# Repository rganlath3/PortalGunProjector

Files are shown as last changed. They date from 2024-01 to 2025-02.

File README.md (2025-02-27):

# Portal Gun Embedded Projector



[]()

A Portal Gun prop featuring an embedded HDMI projector that displays authentic Portal visuals and sounds. This project combines 3D printing, electronics, and software to create a realistic prop that doubles as a portable projector. The portal gun is from popular Valve videogame, Portal / Portal 2.

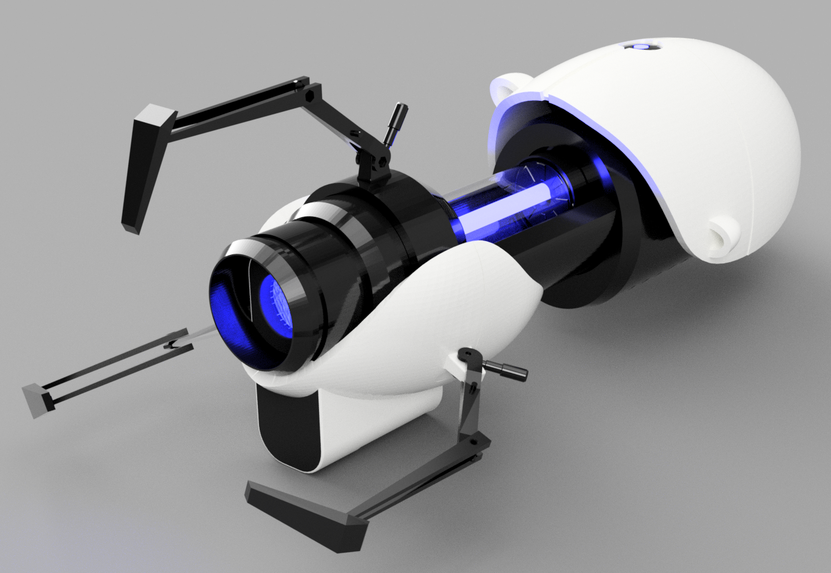
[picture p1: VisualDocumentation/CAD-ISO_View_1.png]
Portal Gun Iso View


<!-- TABLE OF CONTENTS -->
## Table of Contents

<details>
<summary>Table of Contents</summary>

1. [About The Project](#about-the-project)
    - [Design Tools & Requirements](#design-tools--requirements)
        - [Software Requirements](#software-requirements)
        - [Hardware Requirements](#hardware-requirements)
2. [Hardware Development](#hardware-development)
    - [Bill of Materials](#bill-of-materials)
    - [Hardware Used](#hardware-used)
    - [3D Printing the Model](#3d-printing-the-model)
    - [3D Printing Specifications](#3d-printing-specifications)
    - [Model Prep](#model-prep)
    - [Electrical Interconnect Diagram](#electrical-interconnect-diagram)
    - [PCB](#pcb)
    - [Wiring](#wiring)
    - [Power](#power)
3. [Software Development](#software-development)
4. [Getting Started](#getting-started)
    - [Prerequisites](#prerequisites)
    - [Installation](#installation)
    - [Common Issues](#common-issues)
5. [Assets](#assets)
    - [Audio](#audio)
    - [Video](#video)
6. [Roadmap](#roadmap)
7. [Contributing & Donations](#contributing--donations)
8. [License](#license)
9. [Contact](#contact)

</details>

<!-- ABOUT THE PROJECT -->
## About The Project
The idea was to take 3D printing a Portal Gun Prop to the next level of realism. My brother inspired me to create a Prop Portal Gun with an full HDMI Projector inside of the prop. When activated, it displays authentic Portal visuals, produces game-accurate sound effects through integrated speakers, and displays LED effects. The project combines 3D printing, electronics, and software development to create a prop that's both visually accurate and practically useful as a portable projector.

### Design Tools & Requirements

#### Software Requirements
- Python 3.9+ (Programming Language for RPi)
- Raspberry Pi OS Debian v12 (64-bit)
- VS Code (Programming IDE)
- Autodesk Fusion360 (Free CAD Software)
- KiCAD 7 (Open Source PCB Design Software)
- Ultimaker Cura (Free 3D Slicing Software)

#### Hardware Requirements
- Raspberry Pi 4 (8GB RAM recommended)
- 32GB+ SD Card
- 12V Power Supply or 4S Lipo Battery Pack

<p align="right">(<a href="#readme-top">back to top</a>)</p>

## Hardware Development

### Bill of Materials
Coming Soon

### Hardware Used
* Raspberry Pi 4 (SBC)
* Custom RPi HAT PCB (Power and GPIO Distribtuion to Screw Terminals) (See PCB Designs)
* Various Capacitors, Resistors, SMD LEDs, JST Connectors, Wire Crimps, etc.
* Various stranded wire lengths and colors: 16AWG, 22AWG.
* 1x DROK 9V-24V to 5V Step Down Buck Converter, 30W (Powers Pi from Battery Input)
* 1x Songhe 10-32V to 21V Step Up Boost Converter, 150W (Powers Projector from Battery Input)
* 1x 16mm Momentary Metal LED Push Button (Orange)
* 1x 16mm Momentary Metal LED Push Button (Blue)
* 2x 2.1mm DC Barrel Jacks Pair (Power Input)
* 2x SPST 20A Heavy Duty Toggle Switch (Projector Power and Pi Power)
* 1x SPST 5A Mini Toggle Switch (LED Power)
* 1x Individually Addressable 5V NeoPixel
* 1x 1ft. RGB COB Individually Addressable 5V LED Strip 
* Portal Gun 3D Design: (found on thingiverse [here](https://www.thingiverse.com/thing:3579224)) 
* My modifications to the Portal Gun 3D Design.
* 3D Printer: Creality CR-10SProV2

### 3D Printing the Model
I used this portal gun design as a basis for my version. This creator put a lot of work into his design so please give him the attention he deserves: [EVARATE Portal Gun](https://www.thingiverse.com/thing:3579224)

### 3D Printing Specifications

#### Print Settings
- Layer Height: 0.2mm
- Infill: 15% for most parts but 100% for finger parts
- Temperature: 210°C (PLA+)
- Build Plate: 60°C
- Support: Required for overhangs
- Material: eSUN PLA+ or equivalent

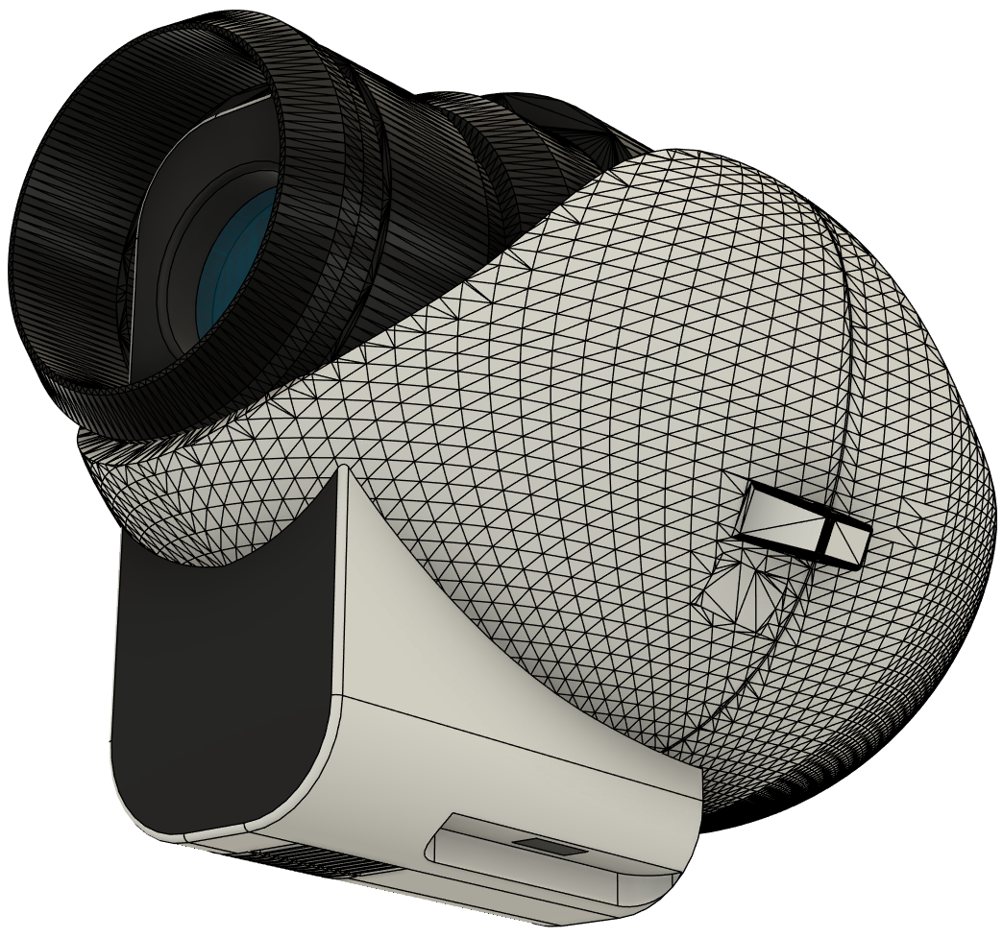
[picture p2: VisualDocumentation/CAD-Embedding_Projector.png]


Besides modifying parts to fit the projector, I also designed an electronics sled to fit the handle base. This is what the DC-DC converters and Raspberry Pi mount to.

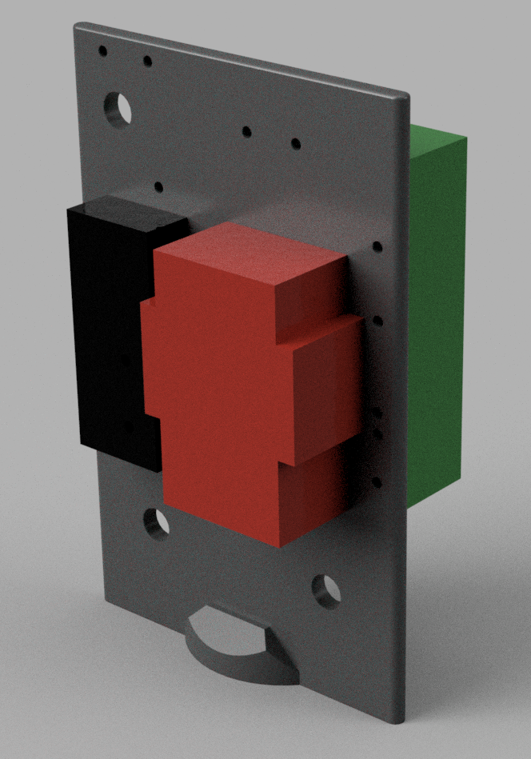
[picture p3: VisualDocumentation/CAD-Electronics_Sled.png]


### Model Prep
Sanding, filler, painting, etc.

* 3M Acryl Putty, 05096 Green or 05098 Red
* Various Sandpaper and Sanding Sponges
* Dremel
* P95 or Better Respirator (don't cheap out on this)
* Filler & Sandable Primer (I use cheap Rust-Oleum)
* Montana Gold Shock White Pure Spray Paint
* Montana Gold Shock Black Spray Paint
* Spray Max USC 2K High Gloss Clearcoat (Automotive Clearcoat, expensive but worth it!)

Once all the parts have been printed, we need to do some post processing to get the prints as smooth as possible. For my first iteration, I used a dremel to manually cut holes in some parts instead of just CADing them out. (I wasn't sure how things would exactly fit.)

*Note: Anytime we are sanding or spray painting, you MUST be wearing that respirator! 
Also try to handle all the parts with rubber gloves so your fingerprints don't mess up the paint coats.*

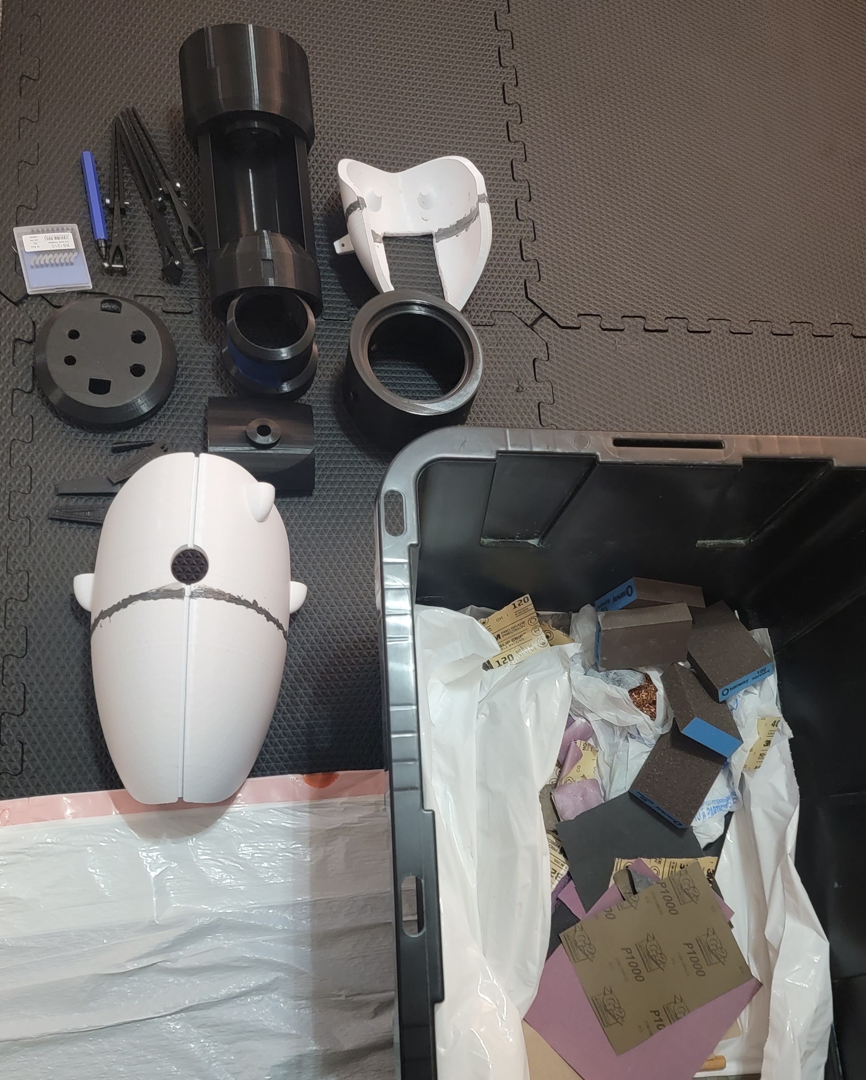
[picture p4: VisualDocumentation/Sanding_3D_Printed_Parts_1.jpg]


Using sanding paper and sponges I used the following grits:
120->220->320->400 using spot putty where needed. Anything above 320 grit should be wet sanded. Then 2x coats of fillable primer spray paint. Then 400 grit. Then 1x coat of fillable primer. Then one more 400 grit. Then 600 grit. Then apply desired paint color (black and white) base coat in many light coats. (3-5 coats) I'd like to try to find an alternate to Montana Gold.

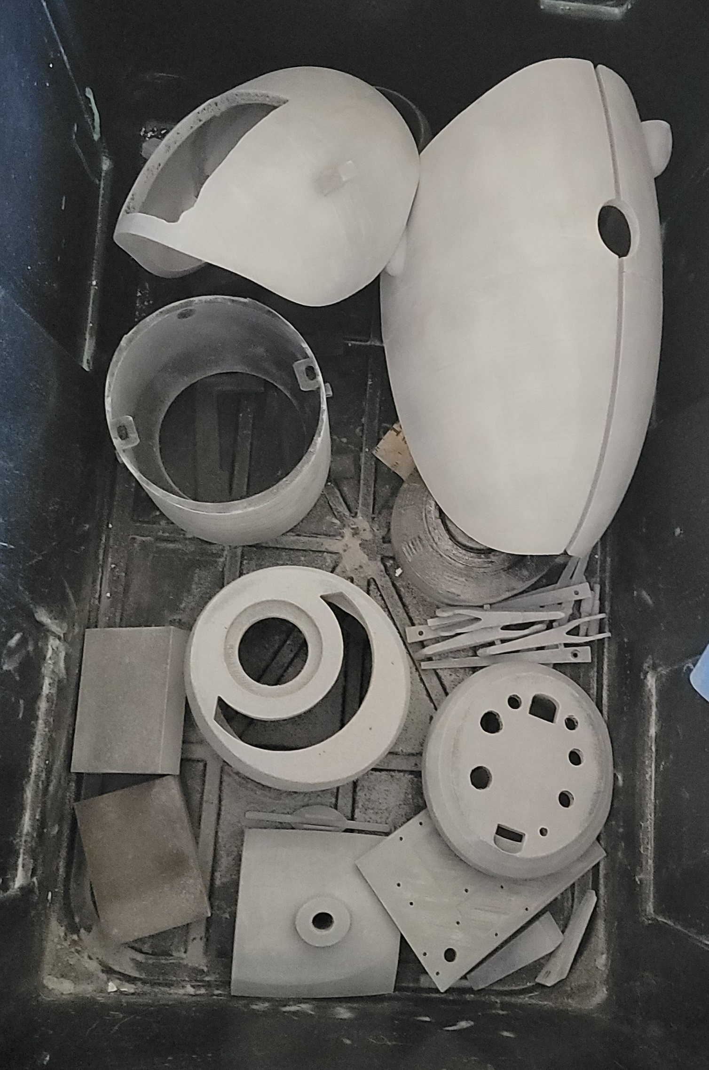
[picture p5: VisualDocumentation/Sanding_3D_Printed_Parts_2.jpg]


Once fully dried, use a damp sponge and wipe the parts. Use 1000 grit to sand down the base coat. 

Optional: Using citadel paints or any acrylic paints, add weathering, scuff marks, or damage. I ended up using a metal file and creating scratches. I finely dry brushed silver paint onto the black parts to create a metallic highlight effect. I also added a white line on the top white part.

Once finished painting, we can now apply layers of clearcoat in a very well ventilated area. This 2K stuff is really toxic so be careful. I ended up using rust-oleum 2x ultracover clear instead which gave a good result but not as nice as 2k would have been. I used gloss clear coat on the white parts and black arms. I used matte clear coat on the black parts. Once fully cured, assembly can begin.

### Electrical Interconnect Diagram
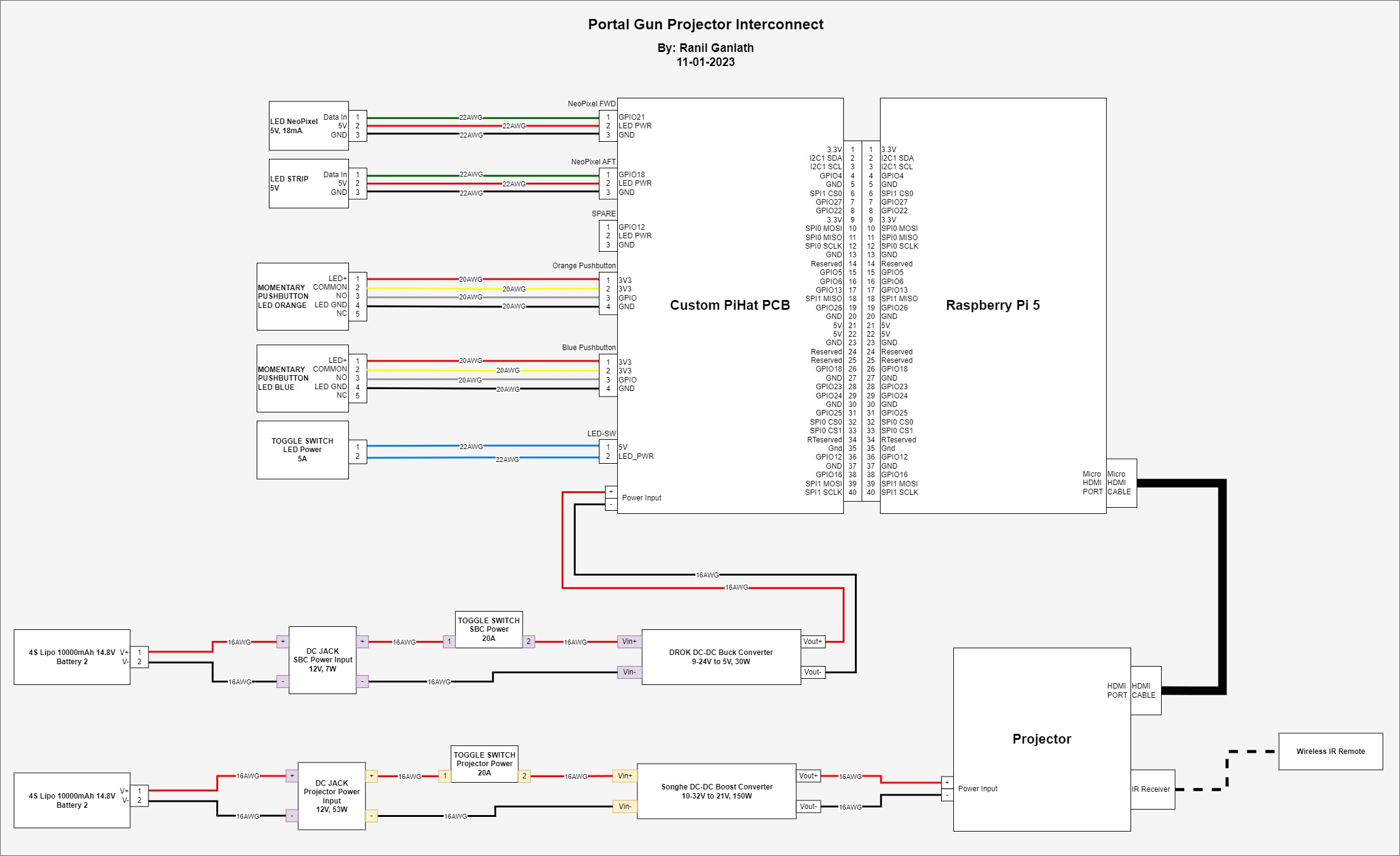
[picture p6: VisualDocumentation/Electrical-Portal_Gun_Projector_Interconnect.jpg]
Electrical Interconnect Diagram


### PCB
I designed a Raspberry Pi Hat PCB that handles powering the board (via 5V pins), powering LEDs, and acting as GPIO inputs/outputs for button inputs and driving neopixels. See Mk2 design for the latest. If I had a chance for another iteration, I would add slotted holes in the center section for the placement of a low profile fan for cooling the raspberry pi.

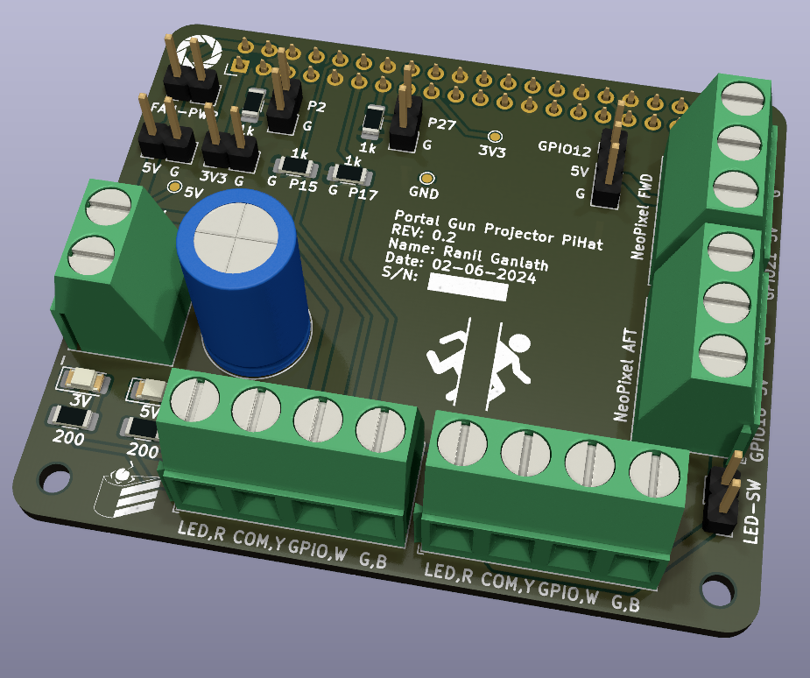
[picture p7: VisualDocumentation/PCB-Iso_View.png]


### Wiring
I used 22AWG and 16AWG for all wiring in the system. 22AWG was used for neopixels and GPIO pins while 16AWG was used for all power lines. 
* Red - Power
* Black - GND
* Green - Data / GPIO

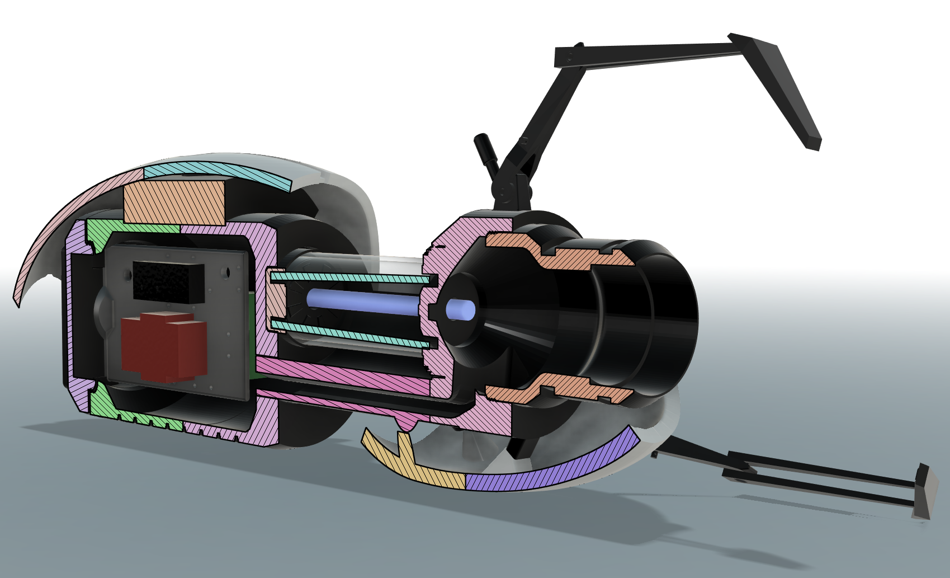
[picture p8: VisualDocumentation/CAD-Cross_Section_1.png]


### Power
I have two separate power circuits: Pi and Projector.

The Pi Circuit runs on 5V. It powers the neopixels, raspberry pi, and push button LEDs.
* Input Voltage: 12V
* Converted Voltage: 5V
* Average Wattage (Script Running): 4.1W
* Theorhetical Max Load: 
* Safety Factor (Max Power * 1.25W): 7W
* Battery Required for 2 hour battery life:

The Projector Circuit runs on 21V. It powers the projector and it's internal speakers.
* Input Voltage: 12V
* Converted Voltage: 21V
* Average Watage (Lamp On): 41.46W
* Theorhetical Max Load:
* Safety Factor (Max Power * 1.25W): 53W
* Battery Required for 2 hour battery life:

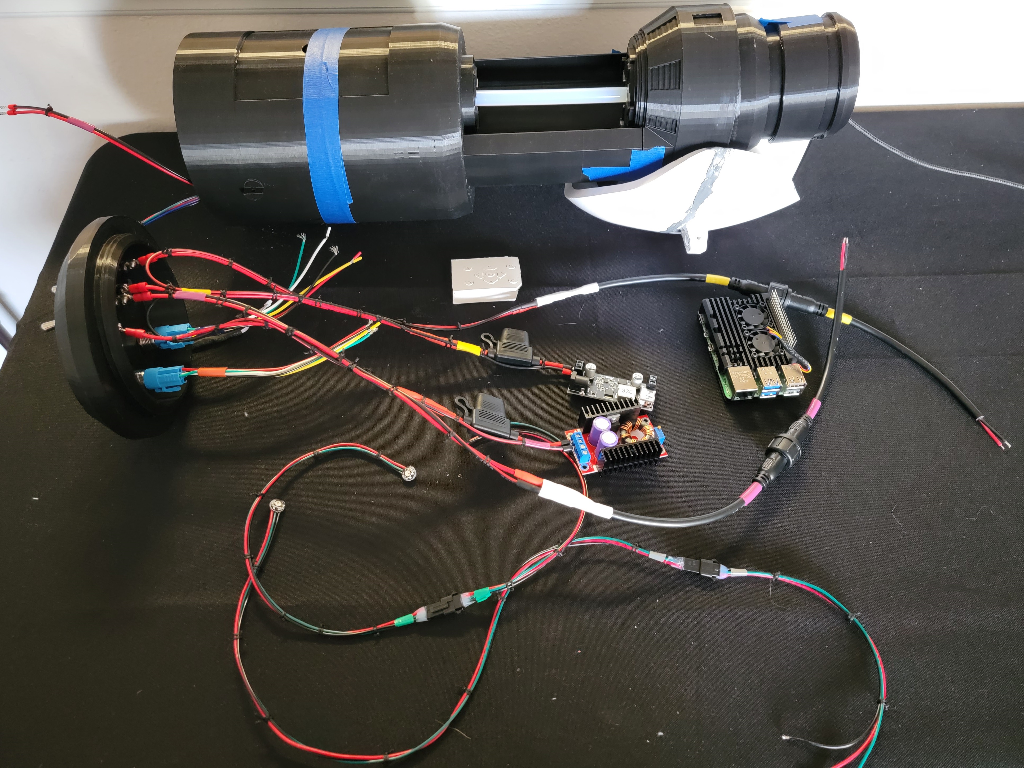
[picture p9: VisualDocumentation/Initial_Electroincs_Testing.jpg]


## Software Development
I am familiar using an Arduino or other MCU to solve all my hardware integration problems. In the past I've used Arduinos + Raspberry Pis when needed (such as for ROS projects). For this project, I wanted to challenge myself to not use any MCUs and to only use the raspberry pi GPIO pins to interact with switches and LED control. It brought up some fun compatibility issues that prevented me from using a Raspberry Pi 5 until libraries were updated. 

***Disclaimer: I am an electrical engineer, so apologies for the chaos that is my programming.***

<!-- GETTING STARTED -->
## Getting Started

* Install Raspberry Pi OS with Desktop (Debian v12) (64-bit)
  * we will use the desktop version for initial setup then switch to the CLI for actual operation. This saves time when troubleshooting things like VLC issues.
* Copy this repo to any desired folder. 
  * For reference, my filepath was: */home/aperture/Documents/PortalGunProjector*

### Prerequisites
*Note: Since Neopixel Usage requires root priviledges, make sure your environment path is configured accordingly. I recommend installing all these python libraries as root (sudo command). It is possible to run sudoless but it requires using only GPIO10 for LEDs*

```bash
# Update System
sudo apt update && sudo apt upgrade -y

# Install Required Packages
sudo apt install git python3-pip vlc -y

# Install Python Dependencies

# Raspberry PI GPIO Control
sudo pip3 install gpiozero

# NeoPixel Drivers
sudo pip3 install adafruit-circuitpython-neopixel

# Pygame
sudo pip3 install pygame

# VLC
sudo apt install vlc

# VLC Python Bindings
sudo pip3 install python-vlc
```

### Installation

1. If you haven't already, clone the repo, to a directory such as: */home/username/Documents/PortalGunProjector*

   ```sh
   git clone https://github.com/rganlath3/PortalGunProjector.git
   ```
2. Install prequisites listed above.

3. Run each test script to test functionality as you build, then run launch.py

<p align="right">(<a href="#readme-top">back to top</a>)</p>

### Common Issues

1. LED Control Fails
```bash
# Check permissions
sudo usermod -a -G gpio $USER
# Reboot required after permission change
```

2. Video Playback Issues
- Ensure micro HDMI port used is closest to USB-C power connector.
- Check video codec compatibility
- Verify file permissions

## Assets

### Audio
The portal gun plays audio out of the hdmi audio output via the projector speakers. Everytime a button is pressed, a random soundclip from a list will play to add some variety to mashing buttons. All audio files are in the "Sounds" folder and are extracted from in game. I do not own these files.

### Video
On bootup a random video and audio line will play as an initialization. On button presses, a random sized orange or blue portal video will play on loop. I manually created these videos by screen recording Garry's Mod and careful editing. Bootup videos are sourced from Portal Gameplay and Trailers from Value and are not owned by me. 

<!-- ROADMAP -->
## Roadmap
- [x] CAD Small Projector
- [x] Modify Portal Gun Designs
- [x] Design electrical interconnect
- [x] 3D Print all parts
- [x] Sanding and post processing on parts
- [x] Painting all parts
- [x] Redesign electrical interconnect
- [x] Create Electronics Sled
- [x] Create wiring harness
- [x] Test LED effects
- [x] Integrate pushbuttons into programming
- [x] Create portal and bootup videos
- [x] Configure code to run on startup
- [x] Add Visual Documentation to GitHub
- [x] Assemble Portal Gun
- [x] Final tests with benchtop power supply
- [ ] Add magnets and external cables
- [ ] Create Battery Harness

<p align="right">(<a href="#readme-top">back to top</a>)</p>

<!-- CONTRIBUTING -->
## Contributing & Donations

Any donation helps to support parts for future open source projects!
[Buy Me a Coffee ☕](https://www.buymeacoffee.com/rganlath)

Contributions are what make the open source community such an amazing place to learn, inspire, and create. Any contributions you make are **greatly appreciated**.

If you have a suggestion that would make this better, please fork the repo and create a pull request. You can also simply open an issue with the tag "enhancement".
Don't forget to give the project a star! Thanks again!

<p align="right">(<a href="#readme-top">back to top</a>)</p>

<!-- LICENSE -->
## License
The contents of this project itself is licensed under CERN-OHL-S-2.0 and the underlying source code used for programming the raspberry pi is licensed under GNU GPLv3. Both of these licenses require attribution.

<p align="right">(<a href="#readme-top">back to top</a>)</p>

<!-- CONTACT -->
## Contact

Ranil Ganlath - ranil.ganlath@gmail.com

Project Link: [https://github.com/rganlath3/PortalGunProjector](https://github.com/rganlath3/PortalGunProjector)

<p align="right">(<a href="#readme-top">back to top</a>)</p>

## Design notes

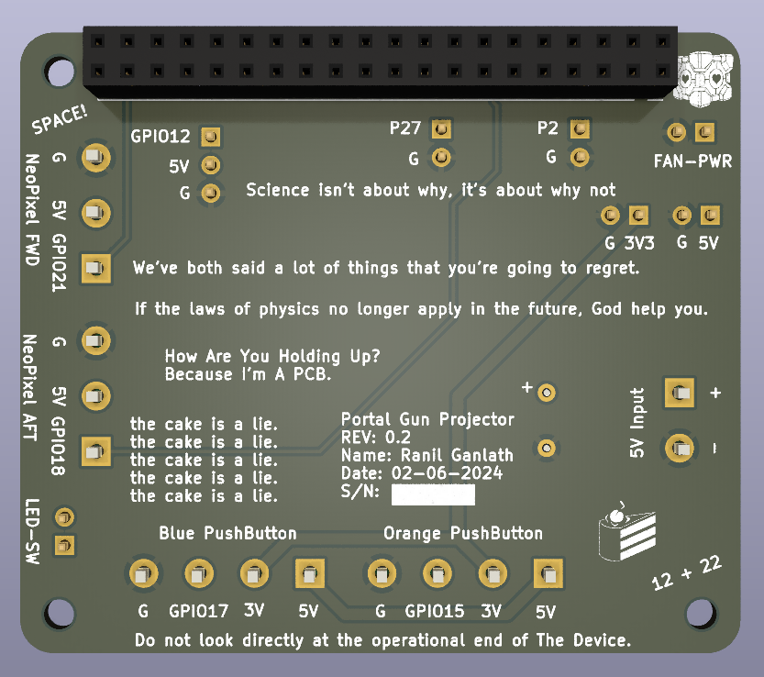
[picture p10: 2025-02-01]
VisualDocumentation/PCB-Bottom_View.png

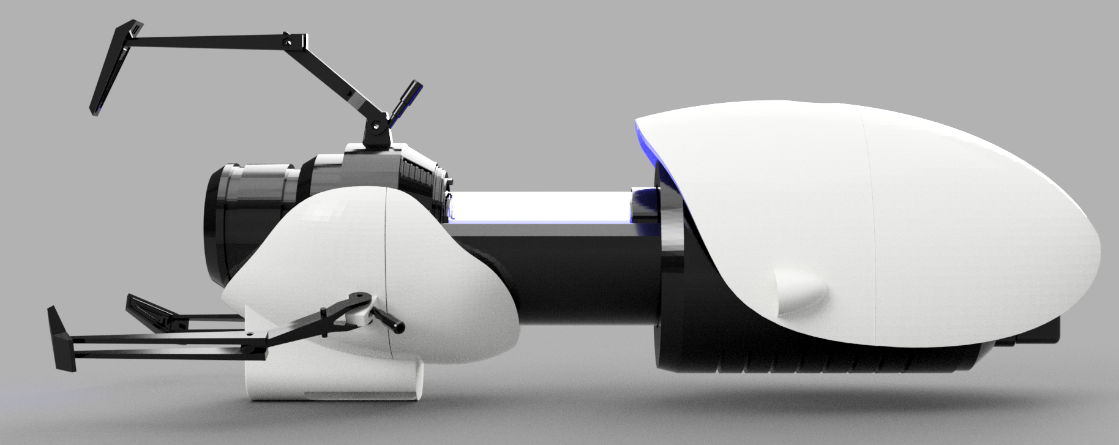
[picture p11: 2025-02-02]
VisualDocumentation/CAD-Side_View.png

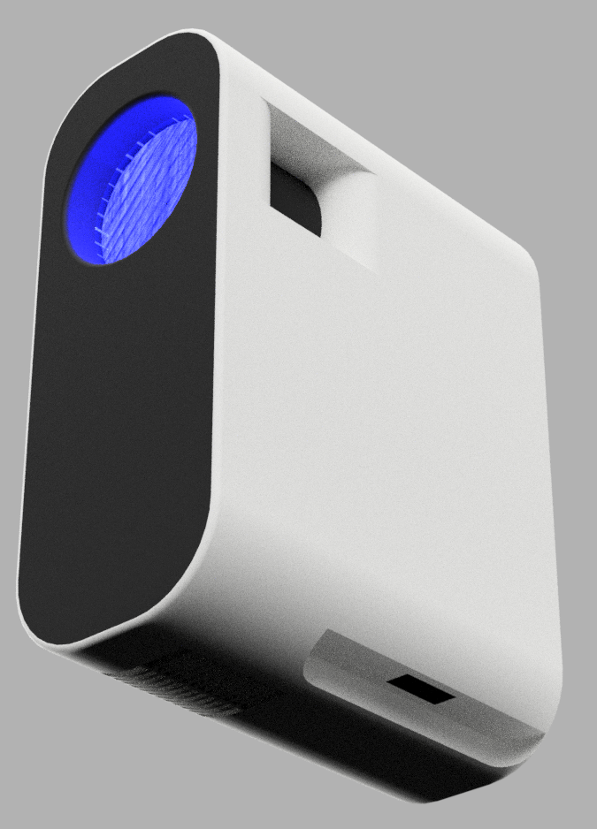
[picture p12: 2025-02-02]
VisualDocumentation/CAD-Projector.png

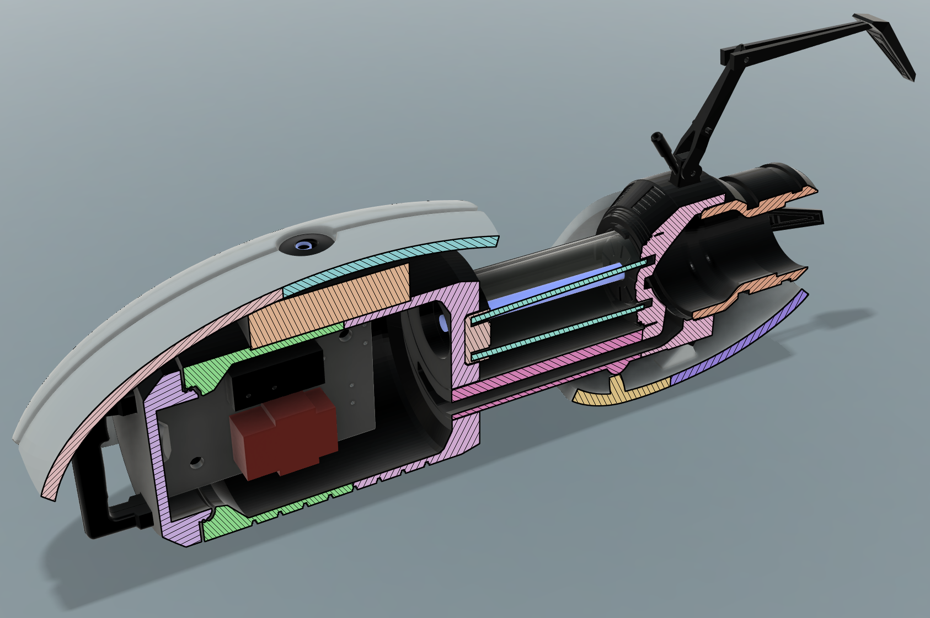
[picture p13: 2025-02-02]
VisualDocumentation/CAD-Cross_Section_2.png

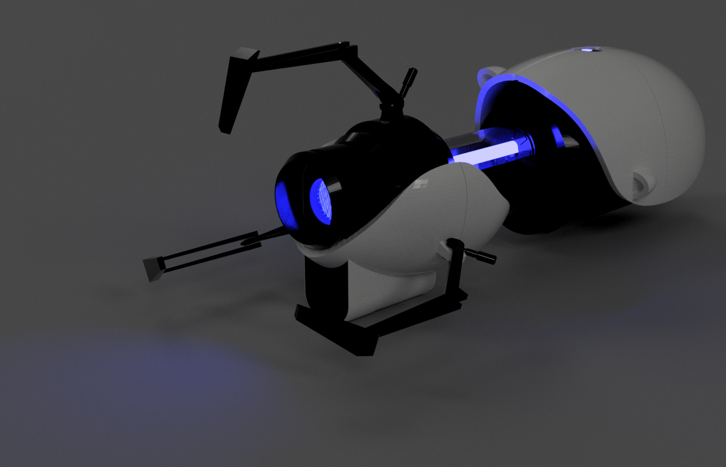
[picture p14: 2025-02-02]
VisualDocumentation/CAD-ISO_View_2.png

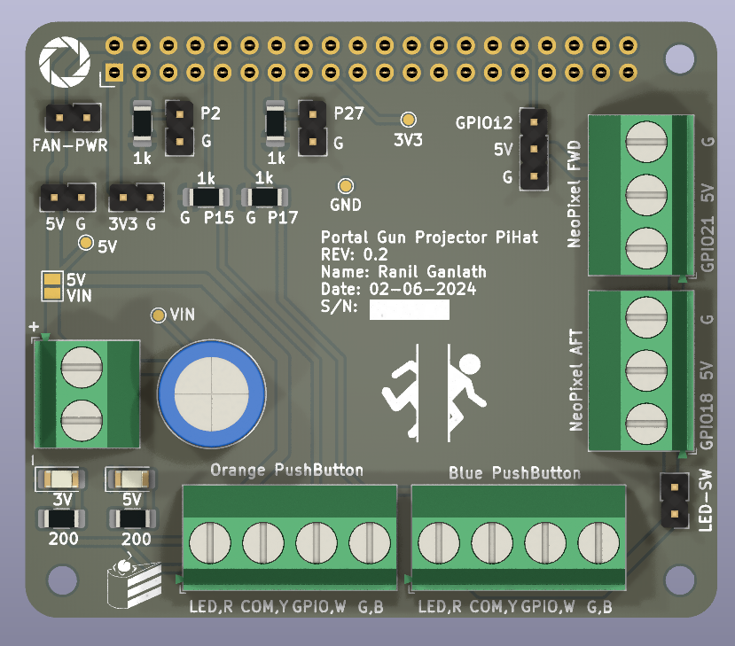
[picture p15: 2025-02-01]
VisualDocumentation/PCB-Top_View.png

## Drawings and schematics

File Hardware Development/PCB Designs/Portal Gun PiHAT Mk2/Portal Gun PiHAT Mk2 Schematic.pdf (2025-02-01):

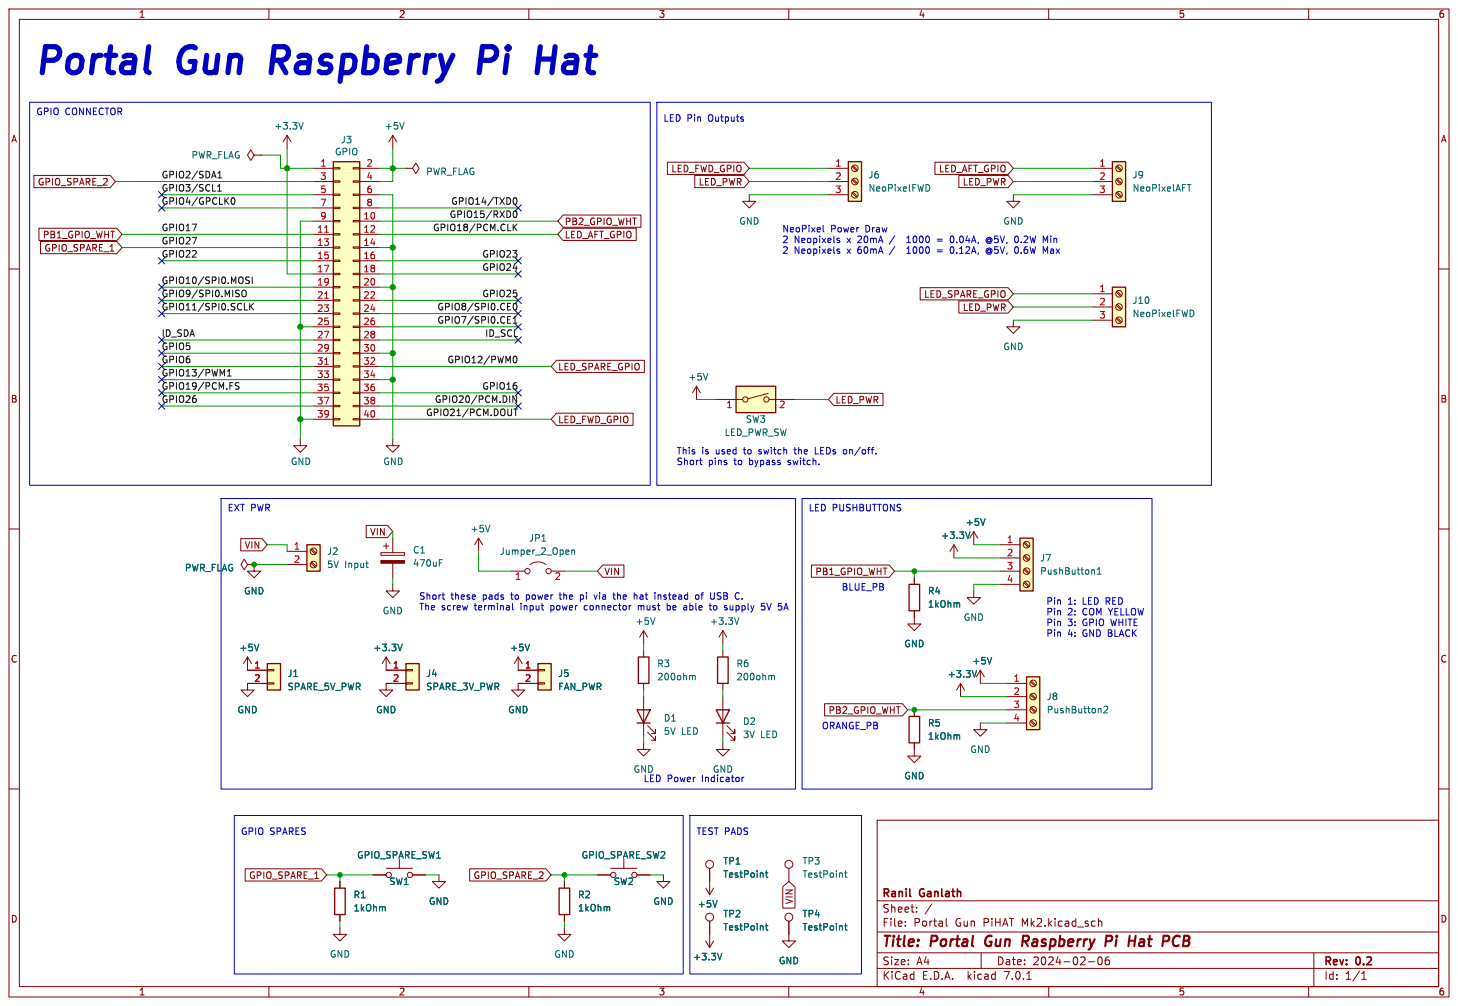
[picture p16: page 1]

LED Pin Outputs EXT PWR
+3.3V GND

ID_SCL GPIO21/PCM.DOUT GPIO8/SPI0.CE0 GPIO16 GPIO12/PWM0 GPIO20/PCM.DIN GPIO7/SPI0.CE1

This is used to switch the LEDs on/off. Short pins to bypass switch. ORANGE_PB

SW1 GPIO_SPARE_SW1 R1
TP4 TestPoint TP3 TestPoint GND GND

Id: 1/1 Title: Portal Gun Raspberry Pi Hat PCB

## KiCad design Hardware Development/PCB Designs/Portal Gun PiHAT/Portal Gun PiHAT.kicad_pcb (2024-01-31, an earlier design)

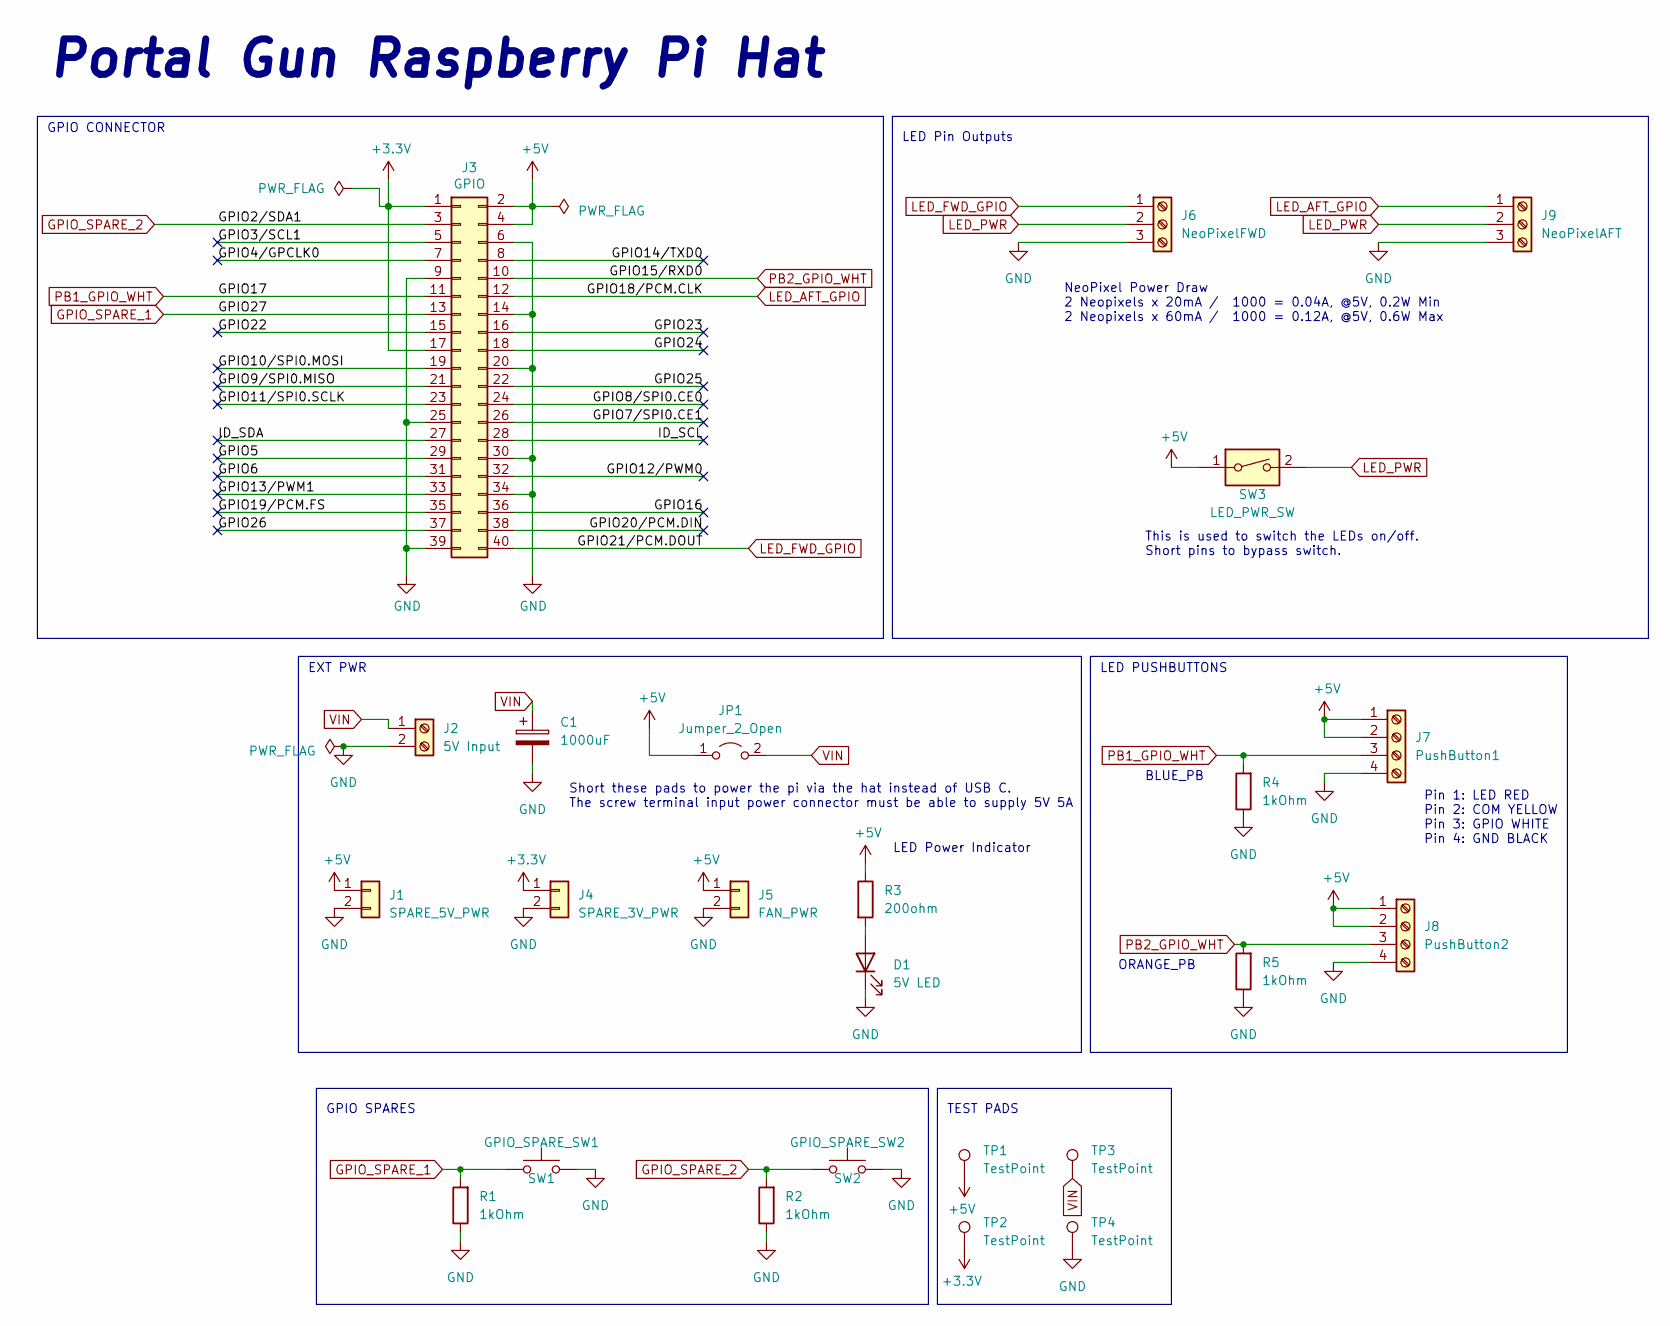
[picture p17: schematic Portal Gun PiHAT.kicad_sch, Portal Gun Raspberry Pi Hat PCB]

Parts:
C1: 1000uF; C_Radial_D10.0mm_H16.0mm_P5.00mm
D1: 5V LED; LED_D3.0mm
J1: SPARE_5V_PWR; PinHeader_1x02_P2.54mm_Vertical
J2: 5V Input; TerminalBlock_Phoenix_MKDS-1,5-2_1x02_P5.00mm_Horizontal
J3: GPIO; PinSocket_2x20_P2.54mm_Vertical
J4: SPARE_3V_PWR; PinHeader_1x02_P2.54mm_Vertical
J5: FAN_PWR; PinHeader_1x02_P2.54mm_Vertical
J6: NeoPixelFWD; TerminalBlock_Phoenix_MKDS-1,5-3_1x03_P5.00mm_Horizontal
J7: PushButton1; TerminalBlock_Phoenix_MKDS-1,5-4_1x04_P5.00mm_Horizontal
J8: PushButton2; TerminalBlock_Phoenix_MKDS-1,5-4_1x04_P5.00mm_Horizontal
J9: NeoPixelAFT; TerminalBlock_Phoenix_MKDS-1,5-3_1x03_P5.00mm_Horizontal
JP1: Jumper_2_Open; SolderJumper-2_P1.3mm_Open_Pad1.0x1.5mm
R1, R2, R4, R5: 1kOhm; R_1206_3216Metric_Pad1.30x1.75mm_HandSolder
R3: 200ohm; R_1206_3216Metric_Pad1.30x1.75mm_HandSolder
SW1: GPIO_SPARE_SW1; PinHeader_1x02_P2.54mm_Vertical
SW2: GPIO_SPARE_SW2; PinHeader_1x02_P2.54mm_Vertical
SW3: LED_PWR_SW; PinHeader_1x02_P2.54mm_Vertical
TP1, TP2, TP3, TP4: TestPoint; TestPoint_Pad_D1.0mm

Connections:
+3V3: J3.1, J3.17, J4.1, TP2.1
+5V: J1.1, J3.2, J3.4, J5.1, J7.1, J7.2, J8.1, J8.2, JP1.1 (A), R3.1, SW3.1, TP1.1
/GPIO3/SCL1: J3.5
/GPIO4/GPCLK0: J3.7
/GPIO5: J3.29
/GPIO6: J3.31
/GPIO7/SPI0.CE1: J3.26
/GPIO8/SPI0.CE0: J3.24
/GPIO9/SPI0.MISO: J3.21
/GPIO10/SPI0.MOSI: J3.19
/GPIO11/SPI0.SCLK: J3.23
/GPIO12/PWM0: J3.32
/GPIO13/PWM1: J3.33
/GPIO14/TXD0: J3.8
/GPIO16: J3.36
/GPIO19/PCM.FS: J3.35
/GPIO20/PCM.DIN: J3.38
/GPIO22: J3.15
/GPIO23: J3.16
/GPIO24: J3.18
/GPIO25: J3.22
/GPIO26: J3.37
/ID_SCL: J3.28
/ID_SDA: J3.27
GND: C1.2, D1.1 (K), J1.2, J2.2, J3.6, J3.9, J3.14, J3.20, J3.25, J3.30, J3.34, J3.39, J4.2, J5.2, J6.3, J7.4, J8.4, J9.3, R1.1, R2.1, R4.1, R5.1, SW1.2, SW2.2, TP4.1
GPIO_SPARE_1: J3.13, R1.2, SW1.1
GPIO_SPARE_2: J3.3, R2.2, SW2.1
LED_AFT_GPIO: J3.12, J9.1
LED_FWD_GPIO: J3.40, J6.1
LED_PWR: J6.2, J9.2, SW3.2
unnamed: D1.2 (A), R3.2
PB1_GPIO_WHT: J3.11, J7.3, R4.2
PB2_GPIO_WHT: J3.10, J8.3, R5.2
VIN: C1.1, J2.1, JP1.2 (B), TP3.1

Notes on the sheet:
LED Power Indicator
This is used to switch the LEDs on/off. Short pins to bypass switch.
GPIO CONNECTOR
LED PUSHBUTTONS
Portal Gun Raspberry Pi Hat
NeoPixel Power Draw 2 Neopixels x 20mA / 1000 = 0.04A, @5V, 0.2W Min 2 Neopixels x 60mA / 1000 = 0.12A, @5V, 0.6W Max
BLUE_PB
ORANGE_PB
LED Pin Outputs
GPIO SPARES
Short these pads to power the pi via the hat instead of USB C. The screw terminal input power connector must be able to supply 5V 5A
Pin 1: LED RED Pin 2: COM YELLOW Pin 3: GPIO WHITE Pin 4: GND BLACK
TEST PADS
EXT PWR

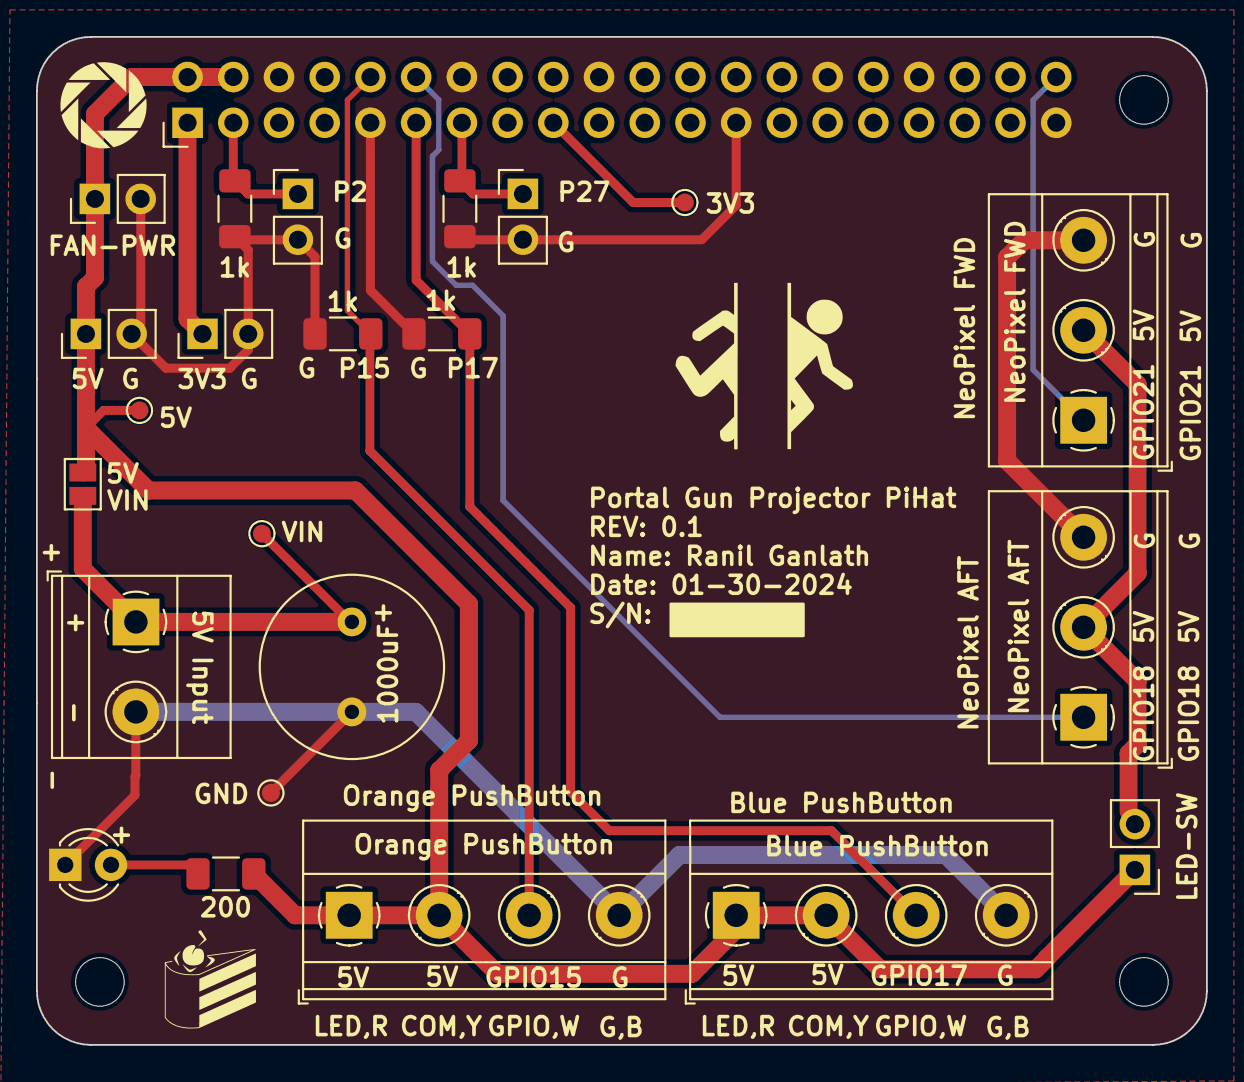
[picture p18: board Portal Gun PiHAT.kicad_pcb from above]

Board: 2 copper layers, 65.0 x 56.0 mm, 27 parts (1 on the bottom side), 12 nets.

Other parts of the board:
MH2, MH3, MH4: MountingHole_2.7mm_M2.5

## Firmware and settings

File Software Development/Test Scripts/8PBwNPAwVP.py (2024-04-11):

#!/usr/bin/env python3

#8 PushButton with Neopixel Animations with Video Playback
#Made by Ranil Ganlath 04-02-2024.
#This script is used for Ranil's Portal Gun Projector Project and contains the following features:
#PushButton Support
#NeoPixel Animations
#Randomized Sounds and Video Playback
#Bootup Animations and Sounds and Video Playback
#File Paths are now relative.

#TO DO
""" 
Add 2nd channel for playing ambience music. This may or may not get paused when a portal blast is played. 
Test if ambience repeats nicely without pause.
Instead of using .desktop for startup, find alternate since it doesn't work with the CLI tool.
 """

import time
import board
import neopixel
from gpiozero import Button
from signal import pause
import pygame
import random
import math
import vlc
import pathlib

#NEOPIXEL SETUP
NUM_PIXELS = 31
Color_Red_Bright = (255, 0, 0)
Color_Orange_Dim = (25, 3, 0)
Color_Orange_Bright = (255, 30, 0)
Color_Blue_Bright = (0, 25, 255)
Color_Blue_Dim = (0, 0, 25)
Color_Teal_Bright = (25,25,255)
Color_Black = (0,0,0)
Color_White = (255, 255, 255)


def getPath(pathType):
    if pathType=="video":
        path = path = str(pathlib.Path(__file__)) #get the file path where this script is stored.
        index = path.rfind("PortalGunProjector")
        if index != -1:
            path = path[:index + len("PortalGunProjector")] + "/Software Development/Videos/"
            return path
        else:
            print("Can't find that path")
    if pathType=="audio":
        path = path = str(pathlib.Path(__file__)) #get the file path where this script is stored.
        index = path.rfind("PortalGunProjector")
        if index != -1:
            path = path[:index + len("PortalGunProjector")] + "/Software Development/Sounds/"
            return path
        else:
            print("Can't find that path")
    print("Error not valid path type")
    return "ERROR"





# AUDIO SETUP
AudioPath = getPath("audio")
R_count = 6 #Store number of R_.wav files in Audio Directory
B_count = 6 #Store number of B_.wav files in Audio Directory
P_count = 7 #Store number of P_.wav files in Audio Directory
A_count = 2 #Store number of R_.wav files in Audio Directory
M_count = 5 #Store number of B_.wav files in Audio Directory
T_count = 5 #Store number of P_.wav files in Audio Directory

# VIDEO SETUP
VideoPath = getPath("video")
VBP_count = 4 #Store number of BP_.mp4 files in Audio Directory
VOP_count = 4 #Store number of OP_.mp4 files in Audio Directory
VBoot_count = 5 #Store number of Boot.mp4 files in Audio Directory

###############################################################
#######################FUNCTIONS DEFINITIONS###################
###############################################################     


def playRandomAudioFile(msg):
    #Takes in a str and based on that randomly plays a song in the sounds directory that starts with str.
    #Types of commands:
    #A is for ambience, play this on a side channel
    #R is for red portals
    #B is for blue portals
    #P is for bootup sounds, play this as a fun quote during bootup.

    global AudioPath,R_count,B_count,P_count
    cmd = AudioPath + msg 
    if(msg == 'R'):
        cmd = cmd + str(random.randint(1,R_count)) #adjust randint values based on number of sounds in directory.
    if(msg == 'B'):
        cmd = cmd + str(random.randint(1,B_count))
    if(msg == 'P'):
        cmd = cmd + str(random.randint(1,P_count))
    if(msg == 'A'):
        cmd = cmd + str(random.randint(1,A_count))
    if(msg == 'M'):
        cmd = cmd + str(random.randint(1,M_count))
    if(msg == 'T'):
        cmd = cmd + str(random.randint(1,T_count))
    cmd = cmd + ".wav"
    SoundFile = pygame.mixer.Sound(cmd)
    SoundFile.play()
    return SoundFile.get_length()

def playVideo(desiredIndex):
    media_player.play_item_at_index(desiredIndex) 

    
def playRandomVideoFile(msg):
    #Takes in a str and based on that randomly plays a video in the sounds directory that starts with str.
    #Types of commands:
    #OP is for orange portals
    #BP is for blue portals

    global VideoPath,VBP_count,VOP_count
    cmd = VideoPath + msg 
    if(msg == 'BP'):
        playVideo(random.randint(0,3))
    if(msg == 'OP'):
        playVideo(random.randint(4,7)) 
        #fix this to not be hardcoded, ex. starting range could be VBP_count to VBP_count + VOP_count
    if(msg == 'BOOT'):
        playVideo(random.randint(8,12)) 
        #fix this to not be hardcoded, ex. starting range could be VBP_count to VBP_count + VOP_count

def callback_BlueButton_Pressed():
    #Runs when blue button is pressed
    #print("Shooting Blue Portal!")
    playRandomVideoFile("BP")
    playRandomAudioFile("B")
    playRandomBlueAnimation()


def callback_OrangeButton_Pressed():
    #Runs when orange button is pressed
    #print("Shooting Orange Portal!")
    playRandomVideoFile("OP")
    playRandomAudioFile("R")
    playRandomOrangeAnimation()



def playRandomOrangeAnimation():
    global Color_Orange_Bright, Color_Orange_Dim, Color_Red_Bright
    Color_Orange_Bright = modify_color(Color_Orange_Bright)
    #Color_Orange_Dim = modify_color(Color_Orange_Dim)
    Color_Red_Bright = modify_color(Color_Red_Bright)

    FWD_Pixel[0] = (255, 30, 0) #Orange
    roll = random.randint(0,2)
    if roll == 0:
        print("Shooting Orange Portal 1!")
        OrangePortalAnim1()
    if roll == 1:
        print("Shooting Orange Portal 2!")
        OrangePortalAnim2()
    if roll == 2:
        print("Shooting Orange Portal 3!")
        OrangePortalAnim3()


def playRandomBlueAnimation():
    global Color_Blue_Bright, Color_Blue_Dim, Color_Teal_Bright
    Color_Blue_Bright =modify_color(Color_Blue_Bright)
    #Color_Blue_Dim =modify_color(Color_Blue_Dim)
    Color_Teal_Bright =modify_color(Color_Teal_Bright)

    FWD_Pixel[0] = (0, 0, 255) #Blue
    roll = random.randint(0,2)
    if roll == 0:
        print("Shooting Blue Portal 1!")
        BluePortalAnim1()
    if roll == 1:
        print("Shooting Blue Portal 2!")
        BluePortalAnim2()

    if roll == 2:
        print("Shooting Blue Portal 3!")
        BluePortalAnim3()




###############################################################
#######################LED ANIMATIONS##########################
###############################################################   
        

def setAllOrangeStatic():
    #Sets all LEDs Orange
    FWD_Pixel[0] = (255, 30, 0) #Orange
    for x in range(0,28):
        AFT_Pixel[x]=(255,30,0)
        
def setAllBlueStatic():
    #Sets all LEDs Blue
    FWD_Pixel[0] = (0, 0, 255) #Blue
    for x in range(0,28):
        AFT_Pixel[x]=(0,0,255)

def BluePortalAnim1():
    for i in range(0,NUM_PIXELS):
        AFT_Pixel.fill(Color_Blue_Dim)
        if i < NUM_PIXELS - 2:
            AFT_Pixel[i] = Color_Blue_Bright
            AFT_Pixel[i + 2] = Color_Blue_Bright
            AFT_Pixel[i + 1] = Color_Teal_Bright
        else:
            AFT_Pixel[NUM_PIXELS - 2] = Color_Blue_Bright
            AFT_Pixel[NUM_PIXELS - 1] = Color_Blue_Bright
        AFT_Pixel.show()
        time.sleep(0.0005)

def BluePortalAnim2():
    timedelay = round(random.uniform(0.005,0.002),4)
    cycle = -1 * math.pi / NUM_PIXELS  # Wave cycle based on the number of pixels
    for t in range(10):
        AFT_Pixel.fill(Color_Blue_Dim)  # Clear pixels
        for i in range(NUM_PIXELS):
            brightness = (math.cos(i * cycle + t * 0.2) + 1) / 2  # Calculate brightness based on sine wave
            AFT_Pixel[i] = tuple(int(brightness/3 * c) for c in Color_Teal_Bright)  # Apply adjusted color to pixel
        AFT_Pixel.show()
        time.sleep(timedelay)
    for x in range(0,NUM_PIXELS):
        AFT_Pixel[x]=(Color_Blue_Dim)

def OrangePortalAnim1():
    timedelay = round(random.uniform(0.0002,0.002),4)
    
    for i in range(0,NUM_PIXELS):
        AFT_Pixel.fill(Color_Orange_Dim)
        if i < NUM_PIXELS - 2:
            AFT_Pixel[i] = Color_Red_Bright
            AFT_Pixel[i + 2] = Color_Red_Bright
            AFT_Pixel[i + 1] = Color_Orange_Bright
        else:
            AFT_Pixel[NUM_PIXELS - 2] = Color_Red_Bright
            AFT_Pixel[NUM_PIXELS - 1] = Color_Red_Bright
        AFT_Pixel.show()
        time.sleep(timedelay)

def OrangePortalAnim2():
    timedelay = round(random.uniform(0.005,0.002),4)
    cycle = -1 * math.pi / NUM_PIXELS  # Wave cycle based on the number of pixels
    for t in range(10):
        AFT_Pixel.fill(Color_Orange_Dim)  # Clear pixels
        for i in range(NUM_PIXELS):
            brightness = (math.cos(i * cycle + t * 0.2) + 1) / 2  # Calculate brightness based on sine wave
            AFT_Pixel[i] = tuple(int(brightness/3 * c) for c in Color_Red_Bright)  # Apply adjusted color to pixel
        AFT_Pixel.show()
        time.sleep(timedelay)
    for x in range(0,NUM_PIXELS):
        AFT_Pixel[x]=(Color_Orange_Dim)

def modify_color(color, max_change=2):
    modified_color = []
    for component in color:
        change = random.randint(-max_change, max_change)
        modified_component = max(0, min(255, component + change))
        modified_color.append(modified_component)
    return tuple(modified_color)        

def OrangePortalAnim3():
    # Initial flicker
    for _ in range(8):
        for i in range(NUM_PIXELS):
            if random.random() < 0.3:
                flicker_brightness = random.randint(0, 50)
                flicker_color = tuple(int(flicker_brightness / 100 * c) for c in Color_Red_Bright)
                AFT_Pixel[i] = flicker_color
            else:
                AFT_Pixel[i] = (Color_Orange_Dim)
        AFT_Pixel.show()
        time.sleep(0.005)
    # Gradual increase in brightness
    for brightness in range(1, 5):
        for i in range(NUM_PIXELS):
            AFT_Pixel[i] = tuple(int(brightness / 100 * c) for c in Color_Orange_Bright)  # Adjust brightness
        AFT_Pixel.show()
        time.sleep(0.001)
    for x in range(0,NUM_PIXELS):
        AFT_Pixel[x]=(Color_Orange_Dim)

# Define animation function
def BluePortalAnim3():
    # Initial flicker
    for _ in range(8):
        for i in range(NUM_PIXELS):
            if random.random() < 0.3:
                flicker_brightness = random.randint(0, 50)
                flicker_color = tuple(int(flicker_brightness / 100 * c) for c in Color_Teal_Bright)
                AFT_Pixel[i] = flicker_color
            else:
                AFT_Pixel[i] = (Color_Blue_Dim)
        AFT_Pixel.show()
        time.sleep(0.005)
    # Gradual increase in brightness
    for brightness in range(1, 5):
        for i in range(NUM_PIXELS):
            AFT_Pixel[i] = tuple(int(brightness / 100 * c) for c in Color_Blue_Bright)  # Adjust brightness
        AFT_Pixel.show()
        time.sleep(0.001)
    for x in range(0,NUM_PIXELS):
        AFT_Pixel[x]=(Color_Blue_Dim)

def rgb_test_animation():
    tuner = 50
    brightness_range = 3
    for brightness in range(0, brightness_range):
        for i in range(NUM_PIXELS):
            AFT_Pixel[i] = (brightness*tuner, 0, 0)  # Set all pixels to current brightness
        AFT_Pixel.show()
        FWD_Pixel[0] = (brightness*tuner, 0, 0)
        time.sleep(0.0001)  # Adjust this value to change the speed of the animation
    for brightness in range(brightness_range, -1, -1):
        for i in range(NUM_PIXELS):
            AFT_Pixel[i] = (brightness*tuner, 0, 0)  # Set all pixels to current brightness
        AFT_Pixel.show()
        FWD_Pixel[0] = (brightness*tuner, 0, 0)
        time.sleep(0.0001)  # Adjust this value to change the speed of the animation
    for brightness in range(0, brightness_range):
        for i in range(NUM_PIXELS):
            AFT_Pixel[i] = (0, brightness*tuner, 0)  # Set all pixels to current brightness
        AFT_Pixel.show()
        FWD_Pixel[0] = (0,brightness*tuner, 0)
        time.sleep(0.0001)  # Adjust this value to change the speed of the animation
    for brightness in range(brightness_range, -1, -1):
        for i in range(NUM_PIXELS):
            AFT_Pixel[i] = (0, brightness*tuner, 0)  # Set all pixels to current brightness
        AFT_Pixel.show()
        FWD_Pixel[0] = (0,brightness*tuner, 0)
        time.sleep(0.0001)  # Adjust this value to change the speed of the animation
    for brightness in range(0, brightness_range):
        for i in range(NUM_PIXELS):
            AFT_Pixel[i] = (0, 0, brightness*tuner)  # Set all pixels to current brightness
        AFT_Pixel.show()
        FWD_Pixel[0] = (0,0,brightness*tuner)
        time.sleep(0.0001)  # Adjust this value to change the speed of the animation
    for brightness in range(brightness_range, -1, -1):
        for i in range(NUM_PIXELS):
            AFT_Pixel[i] = (0, 0, brightness*tuner)  # Set all pixels to current brightness
        AFT_Pixel.show()
        FWD_Pixel[0] = (0,0,brightness*tuner)
        time.sleep(0.0001)  # Adjust this value to change the speed of the animation

def bootupAnimation(duration):
    FWD_Pixel.fill(Color_White)
    start_time = time.monotonic()
    while time.monotonic() - start_time < duration:
        for i in range(NUM_PIXELS):
            for j in range(i):
                AFT_Pixel[j] = Color_White  # Set pixels up to current position to glow color
            AFT_Pixel.show()
            time.sleep(0.01)  # Adjust this value to change the speed of the animation
        AFT_Pixel.fill(Color_Black)  # Clear pixels
    AFT_Pixel.fill(Color_White)  # Clear pixels


###############################################################
###########Setup Function (Runs once on powerup)###############
###############################################################     

print("Starting Bootup")
#Initialize buttons
BlueButton = Button(17,bounce_time=0.1)
OrangeButton = Button(15,bounce_time=0.1)
#Initialize LEDs
FWD_Pixel = neopixel.NeoPixel(board.D21, 1, brightness=1) 
AFT_Pixel = neopixel.NeoPixel(board.D18, 31, brightness=1) #There is actually only 29, but for animations, I am adding an extra 2 LEDs.

#Initialize for video playback
#Path Setup
video_files = []
for file in range(1,VBP_count+1):
    video_files.append("BP"+str(file)+".mp4")
for file in range(1,VOP_count+1):
    video_files.append("OP"+str(file)+".mp4")
for file in range(1,VBoot_count+1):
    video_files.append("BOOT"+str(file)+".mp4")

#at this point, the array is fully built, now let's iterate over it after creating our media players
# creating Instance class object 
player = vlc.Instance() 
# Create a media player object
playman = vlc.MediaPlayer()
playman.set_fullscreen(True)
playman.audio_output_set('dummy') #disable audio
# creating a media list player object 
media_player = vlc.MediaListPlayer() 
media_player.set_playback_mode(2) #repeat current video
# creating a new media list object 
media_list = player.media_list_new() 
#Add all videos to playlist
for video in range(len(video_files)):
    media = player.media_new(VideoPath+video_files[video]) # creating a new media 
    media_list.add_media(media) # adding media to media list 
media_player.set_media_list(media_list) # setting media list to the media player 
media_player.set_media_player(playman)
#Initial Bootup Video


playRandomVideoFile("BOOT")


#Initialize for audio playback
pygame.init()
#Play Bootup Sound
pygame.mixer.Sound(AudioPath+"T2.wav").play()
#RGB NEOPIXEL COLOR TEST
rgb_test_animation()
#Play a random fun quote and return the length of it.
SoundLength = (playRandomAudioFile("P")) #Startup Sound
#Play Neopixel loading animation that is soundlength long.
bootupAnimation(SoundLength)
#Play Ready Sound
pygame.mixer.Sound(AudioPath+"T1.wav").play()
print("Setup Complete, Ready for Portals")


###############################################################
#####################Loop Function#############################
###############################################################


while True:
    #Wait for a button to be pressed, (using when_released since using NC button pin)
    BlueButton.when_released = callback_BlueButton_Pressed
    OrangeButton.when_released = callback_OrangeButton_Pressed
    pause()

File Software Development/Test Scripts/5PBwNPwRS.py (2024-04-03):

#!/usr/bin/env python3

#5 PushButton with Neopixel with Randomized Sounds
#Made by Ranil Ganlath 03-2024.
#This script is used for Ranil's Portal Gun Projector Project and contains the following features:
#PushButton Support
#NeoPixel Static Test
#Randomized Sounds
#Bootup Sounds

import time
import board
import neopixel
from gpiozero import Button
from signal import pause
import pygame
import random
import subprocess

# AUDIO PART
global AudioPath #Stores Audio Directory Folder Path
global R_count #Store number of R_.wav files in Audio Directory
global B_count #Store number of B_.wav files in Audio Directory
global P_count #Store number of P_.wav files in Audio Directory

#Find Audio Directory
AudioPath = "/home/aperture/Documents/PortalGunProjector/Software Development/Sounds/"

#DEVELOPER note I should hardcode these values in to save on startup time.
#Now we count how many of each type of file is in this audio directory to dynamically adjust to new sound files added.
# Get the list of files in the directory that contain a letter like 'R'
result = subprocess.run(['ls', AudioPath], stdout=subprocess.PIPE, universal_newlines=True)
R_count = len([filename for filename in result.stdout.split() if 'R' in filename])
B_count = len([filename for filename in result.stdout.split() if 'B' in filename])
P_count = len([filename for filename in result.stdout.split() if 'P' in filename])
print("Number of files with 'R' in the filename: ", R_count)
print("Number of files with 'B' in the filename: ", B_count)
print("Number of files with 'P' in the filename: ", P_count)



def playRandomAudioFile(msg):
    #Takes in a str and based on that randomly plays a song in the sounds directory that starts with str.
    #Types of commands:
    #R is for red portals
    #B is for blue portals
    #P is for misc sounds

    global AudioPath
    global R_count
    global B_count
    global P_count
    cmd = AudioPath + msg 
    if(msg=='R'):
        cmd = cmd + str(random.randint(1,R_count)) #adjust randint values based on number of sounds in directory. Hardcoded for now since i have better things to do.
    if(msg =='B'):
        cmd = cmd + str(random.randint(1,B_count))
    if(msg == 'P'):
        cmd = cmd + str(random.randint(1,P_count))
    
    cmd = cmd + ".wav" #append .wav to the end
    sound = pygame.mixer.Sound(cmd)
    sound.play()




def callback_BlueButton_Pressed():
    print("Shooting Blue Portal!")
    playRandomAudioFile("B")
    setAllBlueStatic()

def callback_OrangeButton_Pressed():
    print("Shooting Orange Portal!")
    playRandomAudioFile("R")
    setAllOrangeStatic()

def setAllOrangeStatic():
    FWD_Pixel[0] = (255, 30, 0) #Orange
    for x in range(0,28):
        AFT_Pixel[x]=(255,30,0)
        

def setAllBlueStatic():
    FWD_Pixel[0] = (0, 0, 255) #Blue
    for x in range(0,28):
        AFT_Pixel[x]=(0,0,255)

       

pygame.init()

BlueButton = Button(17,bounce_time=0.1) #Blue Pushbutton
OrangeButton = Button(15,bounce_time=0.1) #Orange Pushbutton

FWD_Pixel = neopixel.NeoPixel(board.D21, 1, brightness=1)
AFT_Pixel = neopixel.NeoPixel(board.D18, 29, brightness=1)



#Setup Function (Runs once on powerup)

playRandomAudioFile("P") #Startup Sound
print("Setup Complete")

#Loop Function
while True:
    #Wait for a button to be pressed
    #Using Released due to pullup resistor
    BlueButton.when_released = callback_BlueButton_Pressed
    OrangeButton.when_released = callback_OrangeButton_Pressed
    pause()

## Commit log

2024-01-23 Initial Project Creation
    [Portal Gun PiHAT.kicad_pcb, Portal Gun PiHAT.kicad_sch]
2024-01-23 Added parts from prior kiKAD projects
    [Portal Gun PiHAT.kicad_sch]
2024-01-25 schematic updates
    [Portal Gun PiHAT.kicad_sch]
2024-01-31 KiCad PCBs Finalized
    [Portal Gun PiHAT-B_Cu.gbr, Portal Gun PiHAT-B_Mask.gbr, Portal Gun PiHAT-B_Paste.gbr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]
2024-02-23 PCB Design Updates to fix name formatting and 3V GPIO correction on pushbuttons
    [Portal Gun PiHAT Mk2-B_Cu.gbr, Portal Gun PiHAT Mk2-B_Mask.gbr, Portal Gun PiHAT Mk2-B_Paste.gbr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]
2024-03-20 Updated for longer LED chain
2024-03-20 Button Fixes
2024-03-26 Added new led animations
2024-04-10 Finally got VLC fully working with audio track
2024-04-11 Debug command to turn off LEDs added
2025-02-01 Added PCB visual documentation
2025-02-02 Added CAD screenshots and initial build pictures.
2025-02-08 Added visuals and updated readme.
    [Portal Gun PiHAT Mk2-B_Cu.gbr, Portal Gun PiHAT Mk2-B_Mask.gbr, Portal Gun PiHAT Mk2-B_Paste.gbr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]

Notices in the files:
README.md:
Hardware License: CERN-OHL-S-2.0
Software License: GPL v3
